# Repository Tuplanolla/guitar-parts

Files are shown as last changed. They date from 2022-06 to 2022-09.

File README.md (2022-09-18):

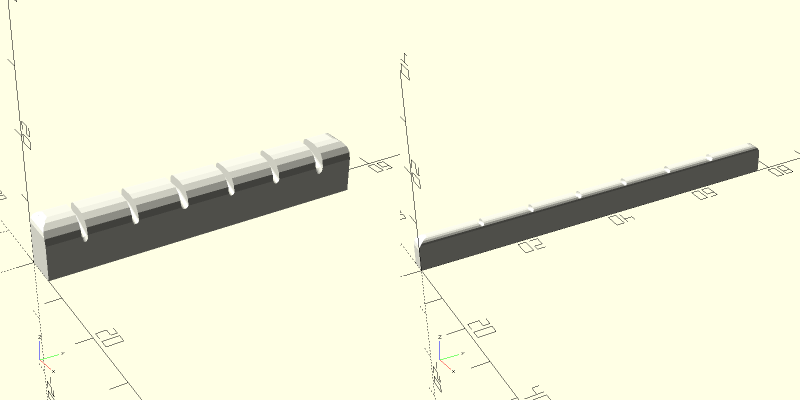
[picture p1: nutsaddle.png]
Cover Art


# Guitar Parts

In this project, we

* measured old and worn parts
  of a classical guitar manufactured by Landola,
* documented the measurements with hasty drawings
  on a computer with no graphical user interface,
* built a parametric model of the parts
  to learn how to use OpenSCAD and
* 3d-printed various realizations of the model
  in order to get acquainted with Prusa i3 MK3S.

Since the guitar was quite wonky,
we managed to produce better replacement parts for it
than any commercially available offerings.
We did not intend the workflow to be as wonky as the guitar,
but it turned out to be like that anyway.
We should also note that "we" mostly refers to Sampsa Kiiskinen,
the sole author of this project, although various members
of Hacklab Jyväskylä were also quite helpful along the way.

## Measurements

Let the `x` axis go along the neck,
growing from the saddle towards the nut.
Let the `y` axis go across the neck,
growing from the first (highest) string towards the last (lowest) one.
Let the `z` axis go through the neck,
growing from the heel towards the fretboard.
Let the strings be numbered from `1` to `6`,
as the strange yet common convention suggests.
Let the unit of measurement be `1` millimeter.

We did not know which strings the guitar originally had,
so we measured them and compared them to new
Augustine Concert Blue (High Tension) and
Augustine Concert Black (Low Tension) strings,
whose dimensions were kindly provided by Strings by Mail.

|     Strings     |  Specifications | Measurements |
| Ordinal | Pitch |   Blue |  Black | Blue | Black |
|--------:|:------|-------:|-------:|-----:|------:|
|       1 | E4    | 0.7112 | 0.7112 |  0.7 |   0.7 |
|       2 | B3    | 0.8128 | 0.8128 |  0.8 |   0.8 |
|       3 | G3    | 1.0160 | 1.0160 |  1.0 |   1.0 |
|       4 | D3    | 0.7747 | 0.7239 |  0.7 |   0.7 |
|       5 | A2    | 0.9144 | 0.8255 |  0.9 |   0.9 |
|       6 | E2    | 1.1430 | 1.1049 |  1.1 |   1.1 |

For the remaining parts,
we used a vernier caliper and a steel ruler
to make sufficiently accurate measurements.
We assumed measurements to have an absolute uncertainty of `0.1`,
with the exception of measurements marked with

* `+` to indicate an uncertainty of `0.2`,
* `+2` to indicate an uncertainty of `0.4`,
* `+3` to indicate an uncertainty of `0.8`,
* `+4` to indicate an uncertainty of `1.6` (actually rounded up to `2`),
* `+5` to indicate an uncertainty of `3.2` (actually rounded up to `4`),
* ...
* `+n` to indicate an uncertainty of `0.1 * 2 ^ n`
  (actually rounded up to `let x = 0.1 * 2 ^ n in
  let r = 10 ^ (floor (log10 (x))) in
  r * ceil (x / r)` in case you wanted the general formula).

### Nut

```
              2.2+3
              |--|
              |  |
    --------- ,--.
    |         |   . ---------
8.8 |      -- ,-. |         |
    | 6.8+ |  |  `. --      | 5.6+3
    |      |  |   |  | 5.6+ |
z   --------- +---+ ---------
^             |   |
|             |---|
+--> x         5.4
```

```
                                 50.0
         |---------------------------------------------------|
         |   0.8    0.9      1.1     0.8    1.0      1.2     |
         |   |-|   |---|   |-----|   |-|   |---|   |-----|   |
         |   | |   |   |   |     |   | |   |   |   |     |   |
      --- ,--. ,---.   ,---.     ,---. ,---.   ,---.     ,--.
1.6+3 |  ,   | |   |   |   |     |   | |   |   |   |     |   .
      -- |   `-'   `---'   `-----'   `-'   `---'   `-----'   |
       ,-+---------------------------------------------------+-.
       | |   | |   |   |   |     |   | |   |   |   |     |   | |
z      ` |---| |---|   |---|     |---| |---|   |---|     |---| '
^      |  3.8+  7.4     7.4       7.4   7.4     7.4       3.8+ |
|      |-------------------------------------------------------|
+--> y                           51.4
```

The widths sum up to 49.8 instead of 50.0.

```
          /.
         /  `-.
        /.     `-.
       /  `-.     `-.  128+4
      /.     `-. 94+4`-.
     /  `-. 58+4`-.     `-.
----.      `-.     `-.     `-.
  | |`-.      `/      `/      `/
--+-+---`-.---/-. ----/-------/----------------
           >-.   `-. /       /  | 34+5 |      |
----.      |o|`-.   /-. ----/----      | 42+5 |
     `-. / `-'   >-.   `-. /           |      | 48+5
        /-. /    |o|`-.   /-. ----------      |
       /   /-.   `-'   >-.   `-.              |
      /.  /   `-.      |o|      `, ------------
z   9.0 `/       `-.   `-'      /
^                   `-.        /
|                      `-.    /
+--> x                    `-.'
```

### Saddle

```
               0.8+3
               |-|
               | |
     --------  ,-.
     |        ,   . --------
8.0+ |        |   |        |
     |        |   |        | 7.0+
     |        |   |        |
z    -------- +---+ --------
^             |   |
|             |---|
+--> x         2.8
```

```
                                 76.8
         |---------------------------------------------------|
         |   0.8    0.9      1.1     0.8    1.0      1.2     |
         |   |-|   |---|   |-----|   |-|   |---|   |-----|   |
         |   | |   |   |   |     |   | |   |   |   |     |   |
         |   ,-.   ,---.   ,-----.   ,-.   ,---.   ,-----.   |
      --- ,--`-'---`---'---`-----'---`-'---`---'---`-----'--.
2.0+3 |  ,                                                   .
      -- |                                                   |
       ,-+---------------------------------------------------+-.
       | |   | |   |   |   |     |   | |   |   |   |     |   | |
z      ` |---| |---|   |---|     |---| |---|   |---|     |---| '
^      | 12.0+  9.8     9.8       9.8   9.8     9.8      12.0+ |
|      |-------------------------------------------------------|
+--> y                          77.0
```

The widths sum up to 78.8 instead of 76.8.

```
                             ,\
                     12+4 ,-'  \
                       ,-'      \
                    ,-'          \
                  \'              ,--------- ------------
                   \           ,-'   .            |     |
      ---- ,--------\.      ,-'  |   |            | 3.2 |
  4.2 |   ,          \.  ,-'  ,--|   |--. ---------     | 13.0
      --- >-----------<-'    /   |   |   .  | 5.0 | 9.8 |
  5.6 |   |            `----'    +---+ --|---     |     |
z   ------+------------------------------+-----------------
^         |           |      |           |
|         |-----------|      |-----------|
+--> x        12.0+2             12.0+2
```

### Fretboard

```
        ,---------------------------------------------------------.
z       | |   |                |          6.2 |   2.6 |  1.8 |  | |
^       | |   | 13.6      11.4 |  +---------(12)-----(1)----(0)-+-+
|       | |   |                |  |  | 5.2
+--> x  +-+-(oo)-------------(20)-+ --
```

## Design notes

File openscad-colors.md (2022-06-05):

# OpenSCAD Colors

The default color is `Gold`.
Its hue rotations are the following.

|       | Start |   End |
| Index | Angle | Angle | Name
|------:|------:|------:|:-----
|     0 |   353 |     4 | `Gold`
|     1 |     4 |    19 | `Yellow`
|     2 |    21 |    27 | `GreenYellow`
|     3 |    27 |    39 | `Chartreuse`
|     4 |    34 |    49 | `LawnGreen`
|     5 |    54 |    83 | `Lime`
|     6 |    90 |   101 | `SpringGreen`
|     7 |   102 |   115 | `MediumSpringGreen`
|     8 |   124 |   133 | `Aqua`
|     9 |   139 |   149 | `DeepSkyBlue`
|    10 |   152 |   158 | `DodgerBlue`
|    11 |   178 |   207 | `Blue`
|    12 |   223 |   234 | `DarkViolet`
|    13 |   235 |   261 | `Fuchsia`
|    14 |   263 |   283 | `DeepPink`
|    15 |   286 |   296 | `Crimson`
|    16 |   298 |   316 | `Red`
|    17 |   321 |   333 | `OrangeRed`
|    18 |   334 |   344 | `DarkOrange`
|    19 |   345 |   353 | `Orange`

Cull the table to get this even palette at 30 degree increments.

|   Old |   New | Start |   End | Rough |
| Index | Index | Angle | Angle | Angle | Name
|------:|------:|------:|------:|------:|:-----
|     0 |     0 |   353 |     4 |     0 | `Gold`
|     3 |     1 |    27 |    39 |    30 | `Chartreuse`
|     5 |     2 |    54 |    83 |    60 | `Lime`
|     6 |     3 |    90 |   101 |    90 | `SpringGreen`
|     8 |     4 |   124 |   133 |   120 | `Aqua`
|    10 |     5 |   152 |   158 |   150 | `DodgerBlue`
|    11 |     6 |   178 |   207 |   180 | `Blue`
|    12 |     7 |   223 |   234 |   210 | `DarkViolet`
|    13 |     8 |   235 |   261 |   240 | `Fuchsia`
|    14 |     9 |   263 |   283 |   270 | `DeepPink`
|    16 |    10 |   298 |   316 |   300 | `Red`
|    17 |    11 |   321 |   333 |   330 | `OrangeRed`

Cull further to get this even palette at 60 degree increments.

|   Old |   New | Start |   End | Rough |
| Index | Index | Angle | Angle | Angle | Name
|------:|------:|------:|------:|------:|:-----
|     0 |     0 |   353 |     4 |     0 | `Gold`
|     5 |     1 |    54 |    83 |    60 | `Lime`
|     8 |     2 |   124 |   133 |   120 | `Aqua`
|    11 |     3 |   178 |   207 |   180 | `Blue`
|    13 |     4 |   235 |   261 |   240 | `Fuchsia`
|    16 |     5 |   298 |   316 |   300 | `Red`

Cull another way to get this even palette at 90 degree increments.

|   Old |   New | Start |   End | Rough |
| Index | Index | Angle | Angle | Angle | Name
|------:|------:|------:|------:|------:|:-----
|     0 |     0 |   353 |     4 |     0 | `Gold`
|     6 |     1 |    90 |   101 |    90 | `SpringGreen`
|    11 |     2 |   178 |   207 |   180 | `Blue`
|    14 |     3 |   263 |   283 |   270 | `DeepPink`

```
$csp = ["Gold", "SpringGreen", "Blue", "DeepPink"];
$csp = ["Gold", "Lime", "Aqua", "Blue", "Fuchsia", "Red"];
$csp = ["Gold", "Chartreuse", "Lime", "SpringGreen", "Aqua", "DodgerBlue", "Blue", "DarkViolet", "Fuchsia", "DeepPink", "Red", "OrangeRed"];
```

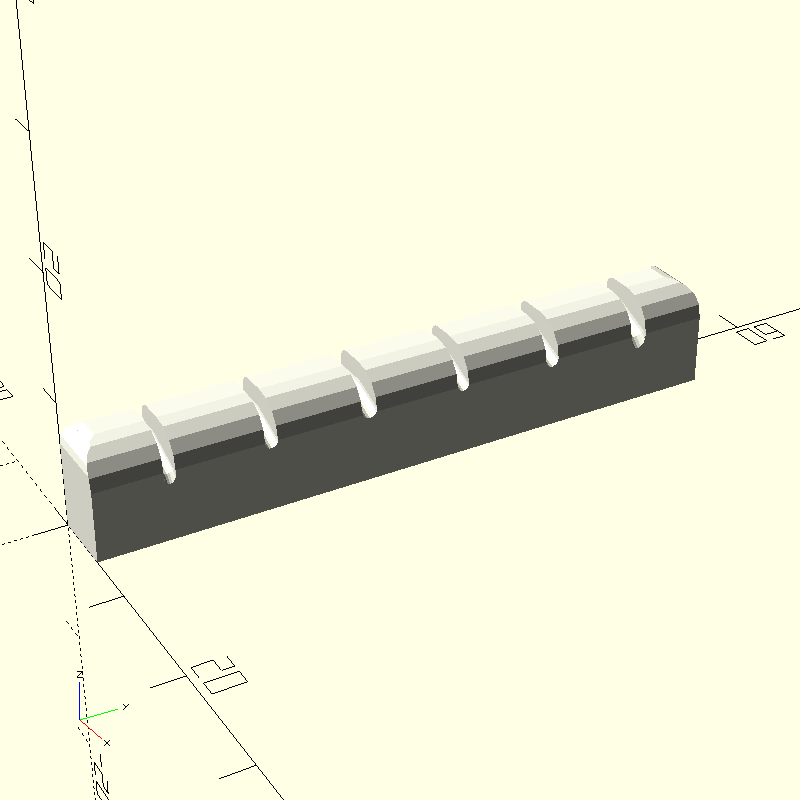
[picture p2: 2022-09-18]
nut.png

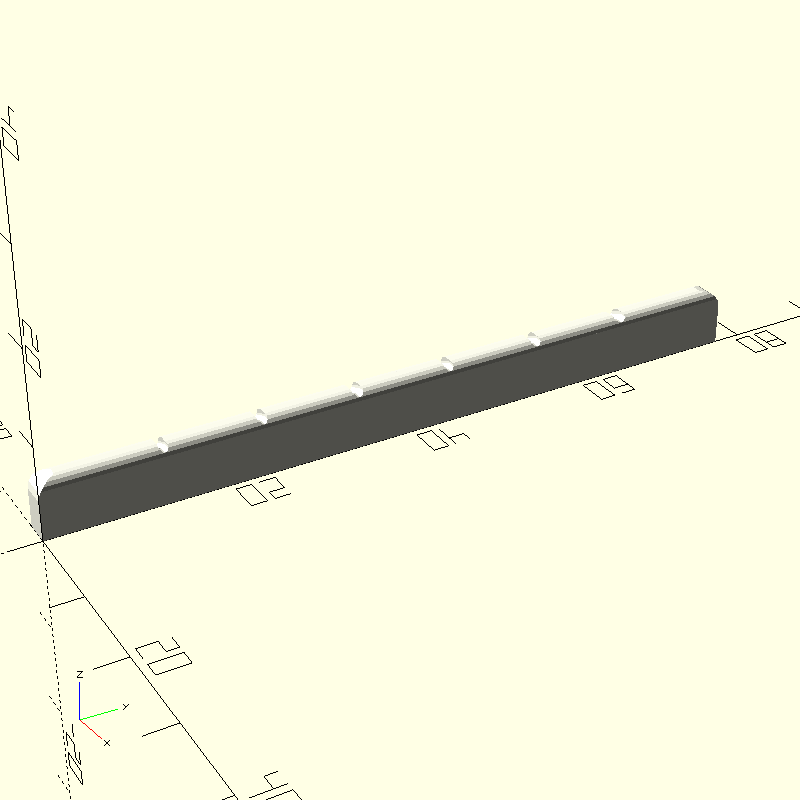
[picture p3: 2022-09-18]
saddle.png

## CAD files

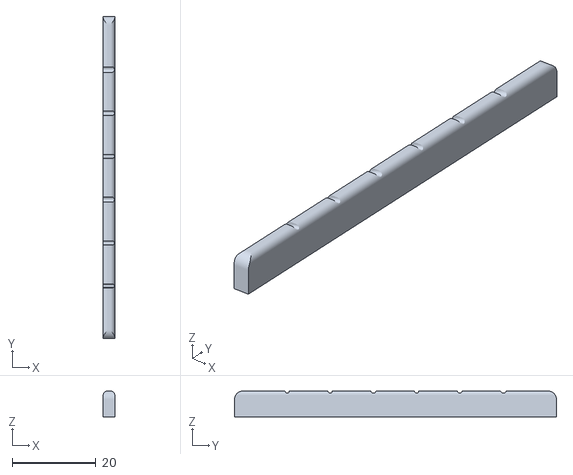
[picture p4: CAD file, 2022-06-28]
saddle.stl
2.80 x 77.0 x 6.20

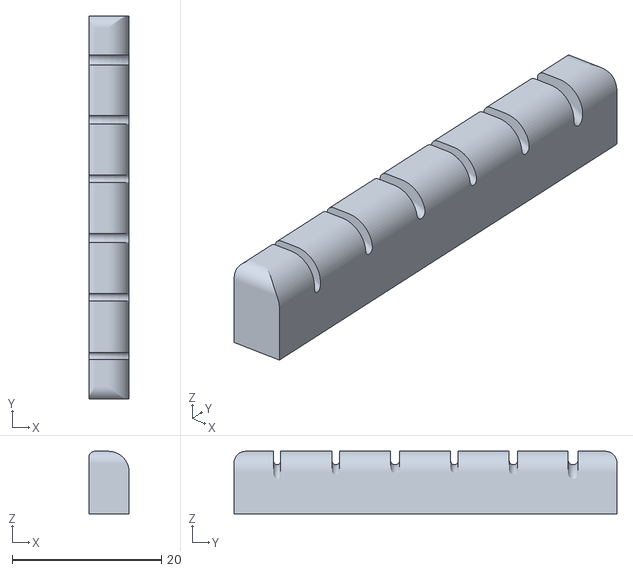
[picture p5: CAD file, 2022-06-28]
nut.stl
5.40 x 51.4 x 8.40

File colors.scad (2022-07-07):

/// The invocation `colorize()` colors its children
/// with the color at the index `$csi` in the palette `$csp`.
module colorize() {
  color($csp[$csi % len($csp)])
    children();
}

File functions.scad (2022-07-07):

/// The invocation `rep(n, v, a)` produces `n` repetitions
/// of the elements of the vector `v`,
/// starting from the accumulator value `a`.
function rep(n, v, a = []) =
  0 < n ? rep(n - 1, v, concat(v, a)) : a;

/// The invocation `rev(v, i, a)` reverses the order
/// of the elements of the vector `v`,
/// starting from the index `i` and the accumulator value `a`.
function rev(v, i = 0, a = []) =
  i < len(v) ? rev(v, 1 + i, concat([v[i]], a)) : a;

/// The invocation `sum(v, i, a)` yields the sum
/// of the elements of the vector `v`,
/// starting from the index `i` and the accumulator value `a`.
function sum(v, i = 0, a = 0) =
  i < len(v) ? sum(v, 1 + i, a + v[i]) : a;

/// The invocation `cumsum(v, i, a)` yields a vector
/// of the cumulative partial sums of the elements of the vector `v`,
/// starting from the index `i` and the accumulator value `a`.
function cumsum(v, i = 0, a = 0) =
  i < len(v) ? concat([a], cumsum(v, 1 + i, a + v[i])) : a;

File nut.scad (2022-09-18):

$e = 0.01;
$fn = 16;

use <functions.scad>
use <nutsaddle.scad>

/// Depth of the part (along the neck).
x_part = 5.4;
/// Width of the part (across the neck).
y_part = 50.0 + 1.4;
/// Height of the part (through the neck).
/// We reduce this to adjust the action.
z_part = 8.8 - 0.4;
/// Depth of the hole that keeps the part in place.
z_hole = 5.2;
assert(z_hole < z_part,
    "Part is shorter than it should be!");

/// How much shallower the grooves should be to account for wear.
z_extra = 0.2;
/// Depths of the grooves on the sharp edge (with room to accommodate wear).
z_groove = 2.0 - z_extra;
echo(z_groove = z_groove);
assert(z_hole + z_groove < z_part,
    "Grooves are deeper than they should be!");
/// How much fitting room the strings should have.
d_extra = 0.1;
/// Diameters of the strings.
d_strings = [0.7112, 0.8128, 1.0160, 0.7747, 0.9144, 1.1430];
/// Widths of the grooves (with room to accommodate fitting).
y_grooves = [for (d_string = d_strings) d_extra + d_string / 2];
echo(y_grooves = y_grooves);
/// Cumulative widths of the grooves.
y_grooves_sum = cumsum(y_grooves);
/// Distances between the grooves.
y_steps = rep(len(y_grooves) - 1, 7.4);
/// Cumulative distances between the grooves.
y_steps_sum = cumsum(y_steps);
/// Distance between the first (and last) groove and the edge.
y_edge = (y_part - y_grooves_sum[len(y_grooves)]
    - y_steps_sum[len(y_grooves) - 1]) / 2;
echo(y_edge = y_edge);
assert(y_edge >= 0,
    "Grooves are wider than they should be!");

/// Angles at which the strings turn
/// from the neck towards their anchoring points.
alpha_anchors = [asin(34 / 58), asin(42 / 94), asin(48 / 128)];
/// Angles at which the grooves turn.
alpha_grooves = concat(alpha_anchors, rev(alpha_anchors));
echo(alpha_grooves = alpha_grooves);
assert(max(alpha_grooves) < 90,
    "Grooves turn more than they should!");
/// Radii of curvature of the grooves.
r_grooves = [for (alpha_groove = alpha_grooves) x_part / sin(alpha_groove)];
echo(r_grooves = r_grooves);
/// Radius of curvature of the round edge (farther away from the neck).
r_anchor = z_part - 5.6;
echo(r_anchor = r_anchor);
/// Radius of curvature of the sharp edge (closer to the neck).
r_neck = 0.8;
/// Radii of curvature of the sides.
r_side = 1.6;
assert(r_anchor + r_neck < x_part && 2 * r_side < y_part,
    "Fillets are larger than they should be!");

color("Ivory")
  grooved_filleted_block(x_part, y_part, z_part,
    z_groove, y_grooves, y_steps, y_edge,
    alpha_grooves, r_grooves, r_anchor, r_neck, r_side);

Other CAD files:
nutsaddle.scad
saddle.scad
shapes.scad

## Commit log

2022-05-29 Initial prototype.
    [bridge.scad, nut.scad]
2022-05-29 New design, but still with poor naming and documentation.
    [nut.scad]
2022-06-05 Varying curvature for each groove.
    [bridge.scad, colors.scad, functions.scad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]
2022-06-06 Polish the model.
    [nut.scad]
2022-06-06 Pretty much finished.
    [functions.scad, nut.scad, saddle.scad]
2022-06-07 Functionalize the model.
    [bridge.scad, nut.scad, nutsaddle.scad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]
2022-06-07 Add missing zeros to match with the table.
    [nut.scad, saddle.scad]
2022-06-09 Notes on uncertainty estimates.
    [nutsaddle.scad]
2022-06-13 Make corrections based on the first print and fit.
    [nut.scad, saddle.scad]
2022-06-13 Add a critical assertion.
    [nut.scad, saddle.scad]
2022-06-17 Corrections after fitting.
    [nut.scad, saddle.scad]
2022-06-28 Add generated files.
    [nut.stl, saddle.stl]
2022-07-07 Separate documentation comments from code comments.
    [colors.scad, functions.scad, shapes.scad]
2022-09-18 Render images automatically.
    [nut.scad, saddle.scad]
2022-09-19 Colors and rendering.
    [nutsaddle.scad, saddle.scad]
